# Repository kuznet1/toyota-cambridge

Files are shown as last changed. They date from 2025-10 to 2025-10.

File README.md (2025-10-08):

# Toyota CamBridge
[Русский](README.ru.md)

## What It Is
A device that allows you to connect a **front camera** to your stock toyota head unit — if a rear one is already installed.  
Tested on the 4th generation RAV4, but will likely work with other models as well.

## How It Works
CamBridge connects to the **CAN bus** and reads data from:
- the gear selector,
- vehicle speed,
- parking sensors.

Based on this data, the device decides when and which camera to activate.

## Operating Logic
**Auto mode** (default):
- When in **R**, the rear camera turns on.
- When in **D**, the front camera turns on if:
    - gear **D** has been engaged less than 2 seconds ago;
    - speed < 10 km/h and the car is moving or stopped for less than 2 seconds;
    - the parking sensor detects an obstacle in front.

**Button (optional):**  
Allows manual switching between modes.
- When in **R** — you can view the front camera.
- When in **D** — you can force the front camera on or disable it entirely.

The LED on the button indicates when one of the alternative modes is active.

## How to Build It

### Circuit
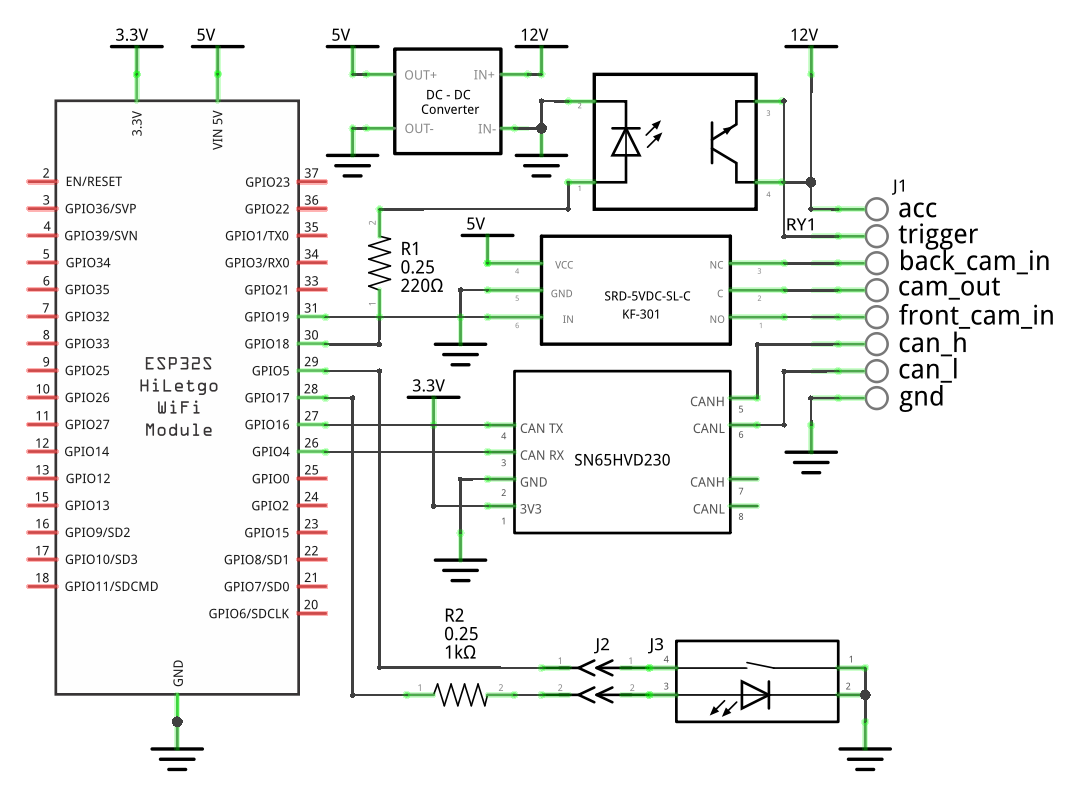
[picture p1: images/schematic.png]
schematic


### Device Pins
| Pin | Description |
|---|---|
| acc | Power input, can be taken from the head unit (ACC) |
| trigger | Video activation signal, connect to the HU instead of the reverse input |
| back_cam_in  | Video input from the rear camera |
| cam_out | Video output, connect to the HU instead of the rear camera input (V+) |
| front_cam_in | Video input from the front camera |
| can_h | CAN bus high |
| can_l | CAN bus low |
| gnd | Ground |

### Head Unit Connection (RAV4 IV)

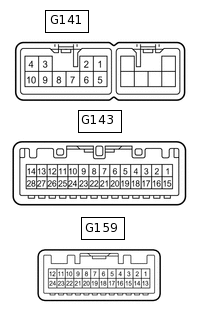
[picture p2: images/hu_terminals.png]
hu


| Signal | Pin | Color  | Description |
|---|---|---|---|
| ACC1 | G141-3  | Gray | +12V when ignition is ON |
| GND1 | G141-7  | Brown  | Power ground |
| REV | G143-2  | Green  | Camera activation input, normally connected to the reverse light signal |
| CANH | G143-9  | Yellow | CAN bus high |
| CANL | G143-10 | White  | CAN bus low |
| V+ | G159-12 | White  | Analog composite video (NTSC) |
| V- | G159-24 | Red | Video signal ground* |

\* To reduce noise, connect the front camera video ground only to "V-".

Other models may have different connectors.

## Device Appearance
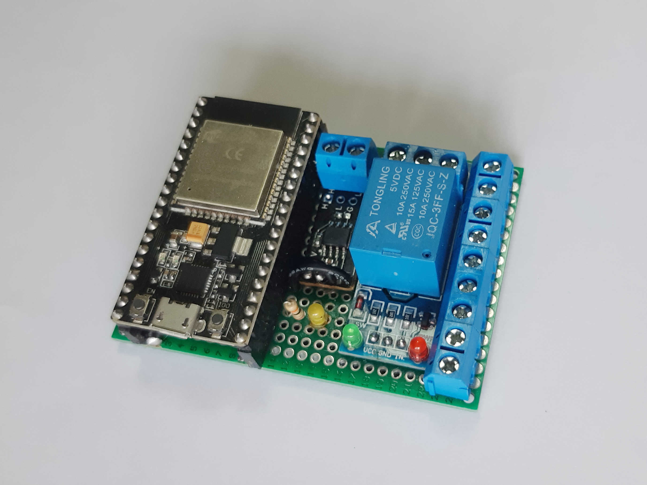
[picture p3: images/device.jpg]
device


## Firmware
1. Install [ESP32 support](https://docs.espressif.com/projects/arduino-esp32/en/latest/installing.html) in Arduino IDE.
2. Select the **NodeMCU-32S** board.
3. Upload the [sketch](toyota-cambridge.ino).

## Tips
- Female “Dupont” jumpers fit directly into the HU connectors, allowing installation without soldering.
- To remove a pin from a HU connector, [lift the lock tab](images/conn-unlock.jpg) by 2 mm and [release the latch](images/conn-pins.jpg) with a needle.
- If the front camera image flickers, it’s likely due to overheating — reducing voltage to 9 V helped in my case.
- For extra reliability, feed the reverse signal through a diode — the rear camera will still activate even if the device fails.

## Components
| Component | Notes | ~$ |
|---|---|---|
| Camera | Available on AliExpress, often with OEM-style bumper mounts | 25 |
| ESP-32S | Any ESP32-based module should work | 3 |
| SN65HVD230 | TWAI CAN transceiver (3.3 V) | 2 |
| HW-307 | 5 V relay module | 1 |
| Mini-360 | DC-DC converter to 5 V | 0.5 |
| PC817 | Optocoupler | 0.5 |
| Resistors | 220 Ω, 1 kΩ | 0.1 |
| KF301 | Terminal blocks, at least 5 pcs; also good for signal ground connections | 0.5 |
| Prototype board | Fits [nicely](images/in-place.jpg) on a 50×70 mm board | 1 |
| Button | OEM-style illuminated non-fixed button with indicator (AliExpress) | 5 |
| **Total** | | **~$40** |

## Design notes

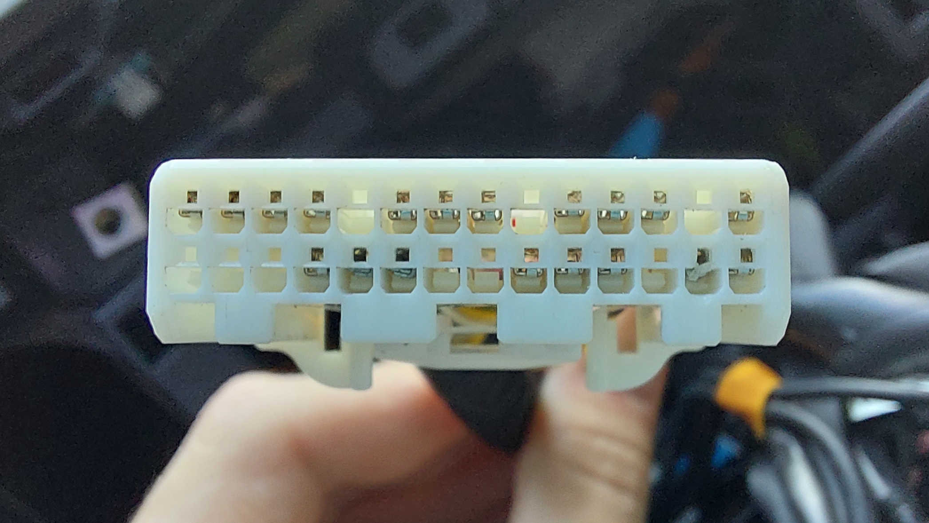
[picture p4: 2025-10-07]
images/conn-pins.jpg

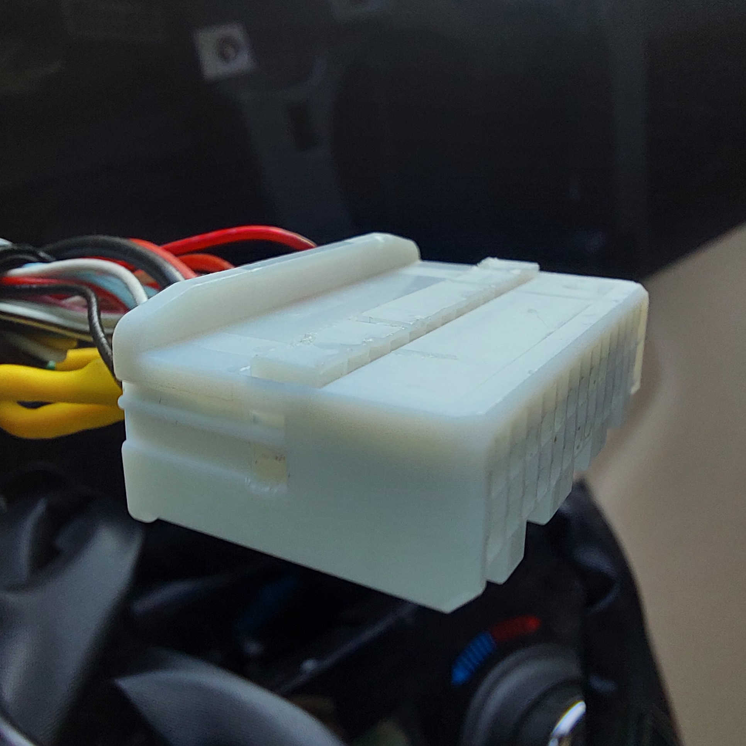
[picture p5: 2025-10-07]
images/conn-unlock.jpg

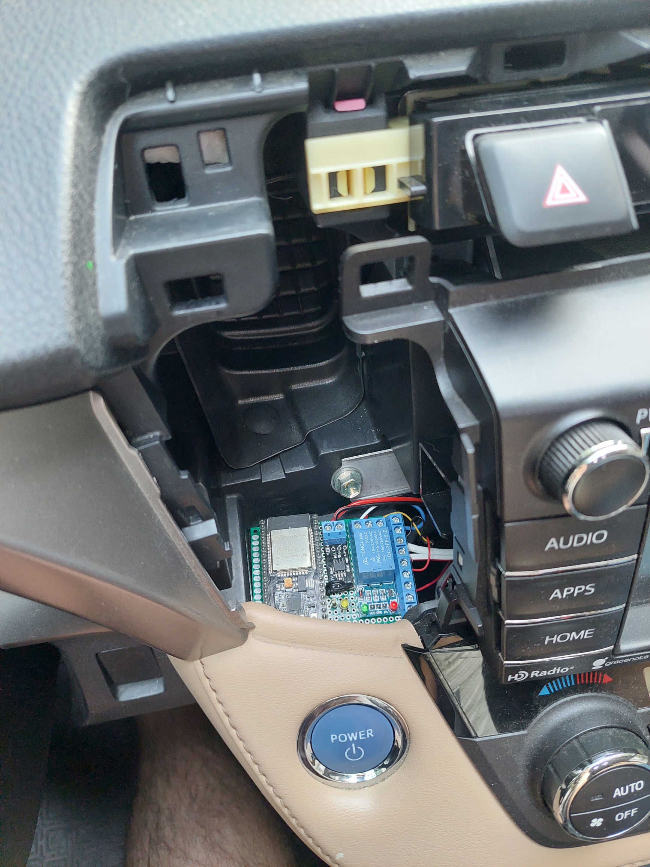
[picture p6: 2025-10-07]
images/in-place.jpg

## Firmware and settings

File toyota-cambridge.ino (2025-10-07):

#include <driver/twai.h>
#include <AceButton.h>
using namespace ace_button;

#define CAN_RX GPIO_NUM_16  // SN65HVD230 TXD -> ESP32 RX
#define CAN_TX GPIO_NUM_4  // SN65HVD230 RXD -> ESP32 TX
#define TRIGGER GPIO_NUM_18
#define RELAY GPIO_NUM_19
#define BUTTON GPIO_NUM_5
#define INDICATOR GPIO_NUM_17

#define PARK    0
#define REVERSE 1
#define NEUTRAL 2
#define DRIVE   3
#define MANUAL  4

enum State {
  AUTO,
  FRONT_ON,
  FRONT_OFF,
};

const State fwdSeq1[] = { AUTO, FRONT_ON, FRONT_OFF };
const State fwdSeq2[] = { AUTO, FRONT_OFF, FRONT_ON };
const State revSeq[] = { AUTO, FRONT_ON};
const State* curSeq = fwdSeq1;
int curSeqIndex = 0;

AceButton button(BUTTON);

void handleButtonEvent(AceButton* button, uint8_t eventType, uint8_t buttonState) {
  if (eventType != AceButton::kEventPressed) {
    return;
  }

  int stateCount = curSeq == revSeq ? 2 : 3;
  curSeqIndex = (curSeqIndex + 1) % stateCount;
  State state = curSeq[curSeqIndex];

  switch (state) {
    case AUTO:
      Serial.println("State: auto");
      digitalWrite(INDICATOR, LOW);
      return;
    case FRONT_ON:
      Serial.println("State: front on");
      digitalWrite(RELAY, HIGH);
      digitalWrite(TRIGGER, HIGH);
      digitalWrite(INDICATOR, HIGH);
      return;
    case FRONT_OFF:
      Serial.println("State: front off");
      digitalWrite(TRIGGER, LOW);
      digitalWrite(INDICATOR, HIGH);
      return;
  }
}

int getLeverPosition(const twai_message_t &msg) {
  static int lastLeverPosition = PARK;

  if (msg.identifier != 0x127) {
    return lastLeverPosition;
  }
  
  if (msg.data_length_code < 6) {
    Serial.printf("Shift lever message is too short: %d bytes\n", msg.data_length_code);
    return lastLeverPosition;
  }

  int leverPosition = msg.data[5] >> 4;

  if (leverPosition == lastLeverPosition) {
    return lastLeverPosition;
  }

  switch (leverPosition) {
    case PARK:
      Serial.println("PARK");
      break;
    case REVERSE:
      Serial.println("REVERSE");
      break;
    case NEUTRAL:
      Serial.println("NEUTRAL");
      break;
    case DRIVE:
      Serial.println("DRIVE");
      break;
    case MANUAL:
      Serial.println("MANUAL");
      break;
    default:
      Serial.printf("UNKNOWN selector code: 0x%X\n", leverPosition);
      break;
  }
  
  lastLeverPosition = leverPosition;
  return leverPosition;
}

float getSpeed(const twai_message_t &msg) {
  static float lastSpeed = 0;

  if (msg.identifier != 0xAA) {
    return lastSpeed;
  }

  if (msg.data_length_code < 8) {
    Serial.printf("Wheel speed message is too short: %d bytes\n", msg.data_length_code);
    return lastSpeed;
  }

  int rawSum = 0;
  for (uint8_t i = 0; i < 4; i++) {
    int wheelSpeedRaw = (msg.data[i * 2] << 8) | msg.data[i * 2 + 1];
    rawSum += wheelSpeedRaw - 6767;
  }

  float speed = (rawSum / 4.0f) * 0.01f;

  if (speed == lastSpeed) {
    return lastSpeed;
  }

  Serial.printf("Speed: %.2f km/h\n", speed);
  lastSpeed = speed;
  return speed;
}


bool frontParktronic(const twai_message_t &msg) {
  static int lastVal = 0;

  if (msg.identifier != 0x396) {
    return lastVal != 0;
  }
    
  if (msg.data_length_code < 3) {
    Serial.printf("Parktronic message is too short: %d bytes\n", msg.data_length_code);
    return lastVal != 0;
  }

  int val = msg.data[1] << 8 | msg.data[2];
  
  if (val == lastVal) {
     return lastVal != 0;
  }

  Serial.printf("Parktronic: %x\n", val);
  lastVal = val;
  return lastVal != 0;
}

State buttonState(int position, bool isFrontCamEnabled) {
  static int lastPosition = PARK;
  if (lastPosition != position) {
    lastPosition = position;
    curSeqIndex = 0;
    digitalWrite(INDICATOR, LOW);
  }

  State state = curSeq[curSeqIndex];
  if (state == AUTO) {
    curSeq = position == REVERSE ? revSeq : isFrontCamEnabled ? fwdSeq2 :fwdSeq1;
  }
  
  return state;
}

void logic(int position, float speed, bool frontParktronic) {
  static long lastEnabledTime = 0;
  static bool isFrontCamEnabled = false;
  static int lastPosition = PARK;
  bool isSwitchedToDrive = lastPosition != DRIVE && position == DRIVE;
  lastPosition = position;

  if (buttonState(position, isFrontCamEnabled) != AUTO) {
    return;
  }

  if (position == NEUTRAL || speed > 9 && speed <= 10) {
    return;
  }

  if (position == DRIVE) {
    digitalWrite(RELAY, HIGH);
  } else {
    digitalWrite(RELAY, LOW);
  }

  if (position == REVERSE) {
    digitalWrite(TRIGGER, HIGH);
    return;
  }

  if (position != DRIVE) {
    digitalWrite(TRIGGER, LOW);
    isFrontCamEnabled = false;
    return;
  }

  long now = millis();
  if (speed > 0 || isSwitchedToDrive || frontParktronic) {
    lastEnabledTime = now;
  }

  isFrontCamEnabled = now - lastEnabledTime < 2000 && speed <= 10 || frontParktronic;
  if (isFrontCamEnabled) {
    digitalWrite(TRIGGER, HIGH);
  } else {
    digitalWrite(TRIGGER, LOW);
  }
}

void setup() {
  delay(100);
  Serial.begin(115200);
  Serial.println("Starting CAN bus...");

  twai_general_config_t g_config = TWAI_GENERAL_CONFIG_DEFAULT(CAN_TX, CAN_RX, TWAI_MODE_LISTEN_ONLY);
  twai_timing_config_t t_config = TWAI_TIMING_CONFIG_500KBITS();
  twai_filter_config_t f_config = TWAI_FILTER_CONFIG_ACCEPT_ALL();

  while (twai_driver_install(&g_config, &t_config, &f_config) != ESP_OK || twai_start() != ESP_OK) {
    Serial.println("Failed to start CAN driver");
    delay(1000);
  }

  pinMode(RELAY, OUTPUT);
  pinMode(TRIGGER, OUTPUT);
  pinMode(BUTTON, INPUT_PULLUP);
  pinMode(INDICATOR, OUTPUT);

  button.getButtonConfig()->setEventHandler(handleButtonEvent);

  Serial.println("CAN driver started successfully");
}

void loop() {
  button.check();
  twai_message_t msg;
  if (twai_receive(&msg, pdMS_TO_TICKS(100)) == ESP_OK) {
    logic(getLeverPosition(msg), getSpeed(msg), frontParktronic(msg));
  }
}

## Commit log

2026-02-12 improve button behavior in park mode
2026-10-25 support for a brake cylinder pressure sensor (precise determination of the moment the vehicle begins to move)
